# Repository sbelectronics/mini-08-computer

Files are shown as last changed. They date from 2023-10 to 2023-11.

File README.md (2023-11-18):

# Mini-08 Computer
### Scott Baker, https://www.smbaker.com/

## Description

The Mini-08 is a Single Board Computer (SBC) based on the Intel 8008 CPU, an 8-bit processor that was designed in approximately 1972. The Mini-08 has the following features

* 8008 CPU
* Up to 128 KB of RAM, mapped in 4K pages
* Up to 128 KB of ROM/EPROM/EEPROM, mapped in 4K pages
* On-board 8251 UART serial port
* 8 Onboard Diagnostic LEDs
* Support for interrupts
* A mostly-RC2014-compatible expansion bus connector

Also featured is an optional display board, which piggybacks on to the mini-08 and adds the following:

* Ten 7-segment hexadecimal display digits
* A 16-digit hexadecimal keypad
* Complex Sound Generator (3 music voices + 1 noise generator)
* Real-Time Clock

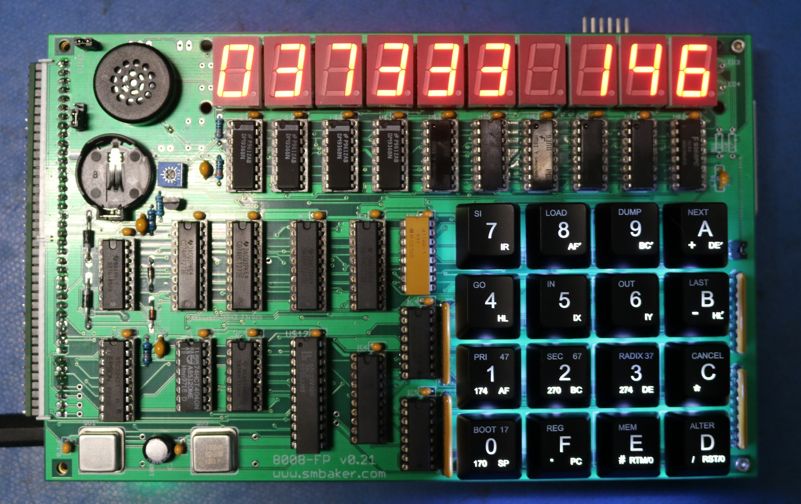
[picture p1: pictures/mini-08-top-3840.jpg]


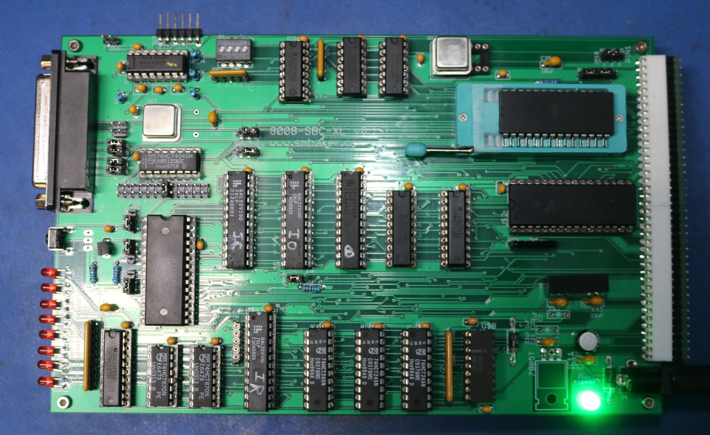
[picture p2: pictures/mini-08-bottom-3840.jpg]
CPU Board


Note that the 4th digit from the right is intentionally blank in these examples in software. The display is showing a
split-octal address (two groups of 3 digits) followed by an octal value (3 digits). All 10 displays are usable if you
decided to use alternate software.

## Alternate Display Board

In case the DM9368N drivers are hard to find or expensive, I have created a variant of the board that uses TIL311 integrated digits and drivers. They're also hard to
find and also expensive!

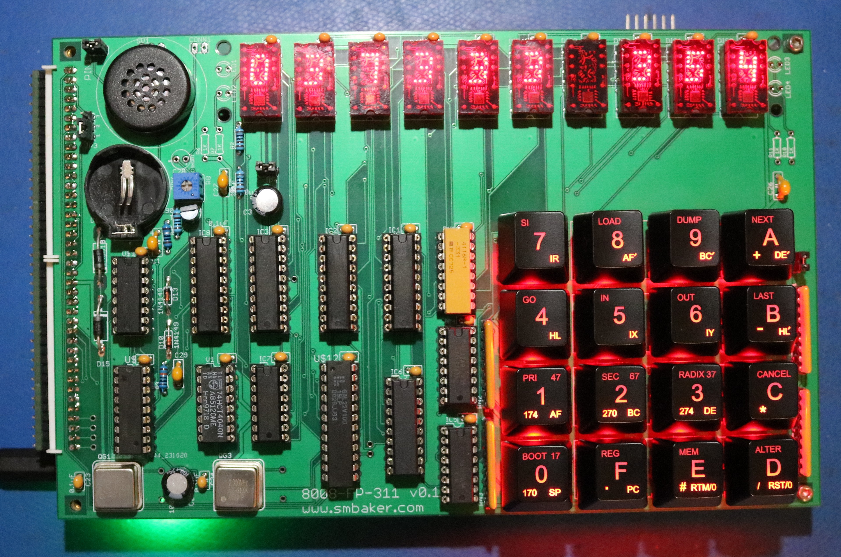
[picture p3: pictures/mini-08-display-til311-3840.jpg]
Display Board


The color of the backlit keys depends on the color of the LEDs you chose. In the TIL311 example, I went with red LEDs for the keys to have a matching
look. The LEDs are at the bottom center of the keys, so the keys are a little bit unevenly lit.

## Jumper Settings

### CPU Board

| Jumper | Position | Default | Description |
| --- | --- | ---| --- |
| SJ1  | 1-2 | X | Two page registers (74HCT670) installed |
| | 2-3 | | Only one page register installed |
| JP2, JP12 |  JP12-1  | | 115200 Baud |
| |  JP12-2  | | 57600 Baud |
| |  JP12-3  | | 38400 Baud |
| |  JP12-4  | | 19200 Baud |
| |  JP12-5  | | 9600 Baud |
| |  JP12-6  | | 4800 Baud |
| |  JP12-7  | | 2400 Baud |
| |  JP12-8  | | 1200 Baud |
| |  JP2-1 | | 600 Baud |
| |  JP2-2 | | 300 Baud |
| |  JP2-3 | | 150 Baud |
| |  JP2-4 | | 75 Baud |
| JP4  | 1-2 | | CTS follows DSR |
| | 2-3 | X | CTS always on |
| JP5  | 1-2 | X | MEMRD controlled by INTCON PLD |
| | 2-3 | | MEMRD directly controlled via bus PLD |
| JP9  | 1-2 | X | RTS is RTS |
| | 2-3 | | RTS is DTR |
| JP10 | 1-2 | X | RC2014-A8 is A12 |
| | 2-3 | | RC2014-A8 is GND |
| JP11 | 1-2 | X | Power-on CPUINT controlled by INTCON PLD |
| | 2-3 | | INTCON PLD bypassed, CPUINT directly controlled by POR |
| JP13 | | Present | Enable 8251 UART |

### Display Board

| Jumper | Position | Default | Description |
| --- | --- | ---| --- |
| SJ1  | | Present | RTC-CS is GND |
| JP1  | | Present | Onboard speaker is enabled |
| JP2  | | Present | Enable keypad backlight |
| JP3  | 1-2 | X | Front panel interrupt to INT pin |
| | 2-3 | | Front panel interrupt to FPINT pin (RC2014-A14) |

## Ports

The following describes the IO ports that I have allocated to various peripherals.

### Input

* 0 BB Serial / Dip Switches (internal)
* 1 Interrupt register (internal)
* 2 8251 UART - Data
* 3 8251 UART - Control
* 4 FP Keyboard
* 5 RTC
* 6 
* 7

### Output

* 8 BB Serial / LEDs (internal)
* 9 
* A FPEI (internal)
* B FPDI (internal)
* C mmap (internal)
* D mmap (internal)
* E mmap (internal)
* F mmap (internal)
* 10 Port multiplexer / RTC-ALE
* 11 Sound
* 12 8251 UART - Data
* 13 8251 UART - Conrol
* 14 
* 15 RTC
* 16 
* 17
* 18 FP Digits 0-1
* 19 FP Digits 2-3
* 1A FP Digits 4-5
* 1B FP Digits 6-7
* 1C FP Digits 8-9
* 1D FP Dots 0-7
* 1E FP Blanks 0-7
* 1F FP Dots 8-9, Blanks 8-9

Note to self: 18-1F were the IO Mapper on the H8 board. Some of my code may still output stuff to those ports.

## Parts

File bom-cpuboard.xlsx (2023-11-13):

Part | Value | Device | Package | Description | Mouser
C1,C3-C18,C20,C24-C38,C42 | 0.1uF | C-US025-025X050 | C025-025X050 | Various 0.1uF monolithic ceramic bypass caps
C19 | 100uf | CPOL-USE2.5-7 | E2,5-7 | POLARIZED CAPACITOR, American symbol | 667-ECE-A1EKS101I
C21,C22,C39-C44 | 10uF | C-US050-025X075 | C050-025X075 | Various 10uF monolithic ceramic caps, 5.08mm pitch
C23 | 1uF | C-US050-025X075 | C050-025X075 | Optional additional power supply filtering
D1 | 9V | TVS | DO15-12 | Optional 9V TVS protection diode | 576-SA9.0A
D4 | 5V | TVS | DO15-12 | Optional 5V TVS protection diode | 576-SA5.0A
DC1 |  | DCDC-SINGLETMV | TMV | DC-DC CONVERTER (if not using 7909 regulator) | 209-IVB0105S09
IC1 | 74HCT74N | 74HCT74N | DIL14 | Dual D type positive edge triggered FLIP FLOP, preset and clear | 595-SN74HCT74NE4
IC2 | 74HCT367N | 74HCT367N | DIL16 | Hex BUS DRIVER, 3-state | 595-CD74HCT367E
IC3,IC9,IC10 | 74HCT245N | 74HCT245N | DIL20 | Octal BUS TRANSCEIVER, 3-state | 595-SN74HCT245N
IC4 | 8251A | 8251A | DIL28-6 | Universal Syncronous/Asynchronous Receiver/Transmitter (USART) | jameco, utsource, ebay, etc
IC5,IC24 | 74HCT670N | 74HCT670N | DIL16 | 4 by 4 REGISTER FILES, 3-state | utsource, ebay, etc
IC6 | MAX202 | MAX202 | DIL16 | RS232 TRANSCEIVER | 700-MAX202CPE
IC7,IC12,IC18 | 74HCT273N | 74HCT273N | DIL20 | Octal D type FLIP FLOP, clear | 595-SN74HCT273N
IC11 | 7805T | 7805T | TO220H | +5V Regulator.Recommend pololu S13V15F5 instead
IC14 | 74HCT02N | 74HCT02N | DIL14 | Quad 2-input NOR gate | 595-SN74HCT02NE4
J4 | VIN | DCJACKNOSLOTS-BIGGER | DCJACK_NOSLOTS_BIGGER | DC POWER JACK
JP* |  |  |  | Various 1x2, 1x3, or 2x2 jumpers -- buy large and cut to size
LED0-LED7 |  | LED3MM | LED3MM | LED - 3MM RED
LED8 |  | LED5MM | LED5MM | LED - 5MM GREEN
QG1 | 4.9152MHz | XO-8 | DIL08S | Oscillator | 520-2100AX-049
QG3 | 1MHz | XO-8 | DIL08S | Oscillator | 520-TCH100-X
R1,R2 | 1K | R-US_0204/7 | 0204/7 | RESISTOR, American symbol
R3 |  | R-US_0204/2V | 0204V | RESISTOR, American symbol
R4,R5,R15 | 10K | R-US_0204/7 | 0204/7 | RESISTOR, American symbol
R6,R14,R23 | 2.2K | R-US_0204/2V | 0204V | RESISTOR, American symbol
RN1,RN7 | 1K | G08R | SIL9 | 1K by 8 resistors (9-pin) SIL RESISTOR
RN2 |  | G04R | SIL5 | SIL RESISTOR
RN3,RN6,RN9 | 10K | G04R | SIL5 | 10K by 8 resistors (9-pin) SIL RESISTOR
S2 |  | DS04 | DS-04 | 4-pin dip switch | 710-418117270904
SV1 |  | MA03-1 | MA03-1 | PIN HEADER
SV2 |  | MA05-1 | MA05-1 | PIN HEADER
SV3 |  | MA06-1 | MA06-1 | PIN HEADER
U$1 | ATF22V10-INTREG | ATF22V10 | DIL24-3 | GAL22V10D programmed with PLD/intreg | utsource, ebay, aliexpress "GAL22V10D-15LP"
U$2 | AS6C4008 | AS6C4008 | DIL32 | RAM, either AS6C4008 or AS6C1008 should work | 913-AS6C4008-55PCN
U$3 | ATF22V10-INTCON | ATF22V10 | DIL24-3 | GAL22V10D programmed with PLD/intcon | utsource, ebay, aliexpress "GAL22V10D-15LP"
U$4 | ATF22V10-BUS | ATF22V10 | DIL24-3 | GAL22V10D programmed with PLD/bus | utsource, ebay, aliexpress "GAL22V10D-15LP"
U$5 | ATF22V10-IO | ATF22V10 | DIL24-3 | GAL22V10D programmed with PLD/io | utsource, ebay, aliexpress "GAL22V10D-15LP"
U$6 | BUTTON_RA | BUTTON_RA | BUTTON_RA
U$7 | MCP130H | MCP130H | TO92- | Reset Supervisor IC | 579-MCP130-450HI/TO
U$8 | 8008 | 8008-FLP | DIL18 | 8008 CPU | ebay, aliexpress. ** be careful of counterfeits **
U$10 | RC2014 | RC2014 | SIP40 | 40-pin right angle sip socket
U$21 | 28C512-256 | 28C512-256 | DIL32-28-6-ZIF-SOCKET | EPROM/EEPROM/FL:ASH: 27C256, 28C256, 27C512, or 39SF010 | 804-39SF010A7CPHE
V1 | 744040N | 744040N | DIL16 | 12-bit asynchronous binary COUNTER
X2 |  | F25HP | F25HP | 25 pin female connector

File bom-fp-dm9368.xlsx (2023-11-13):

Part | Value | Device | Package | Description | Mouser
BAT1 |  | BATTERY20PTH | BATTCOM_20MM_PTH | Battery Holders
C1,C26,C27,C29 | 10uF | C-US050-025X075 | C050-025X075 | Various 10uF monolithic ceramic caps, 5.08mm pitch
C2-C24,C30,C31 | 0.1uF | C-US025-025X050 | C025-025X050 | Various 0.1uF monolithic ceramic bypass caps
C25 | 100uf | CPOL-USE2.5-7 | E2,5-7 | POLARIZED CAPACITOR, American symbol
C28 | SHORT | CPOL-USE2.5-5 | E2,5-5 | POLARIZED CAPACITOR, American symbol
D0-D9 |  | 7SEG-CK | 7SEG-13 | 7-segment DISPLAY | 859-LTS-6980HR
D10,D13 | 1N4149 | 1N4148DO35-7 | DO35-7 | DIODE
D14,D15 | 1N5819 | DIODE-DO15-12 | DO15-12 | DIODE
IC1,IC2,IC3,IC8 | 74HCT273N | 74HCT273N | DIL20 | Octal D type FLIP FLOP, clear
IC4,IC5 | 74LS148N | 74LS148N | DIL16 | 10-line to 4-line and 8-line to 3-line PRIORITY ENCODER
IC6 | 74HCT245N | 74HCT245N | DIL20 | Octal BUS TRANSCEIVER, 3-state
IC7 | 74ACT138N | 74ACT138N | DIL16 | 3-line to 8-line DECODER/DEMULTIPLEXER
JP* |  |  |  | Various 1x2, 1x3, or 2x2 jumpers -- buy large and cut to size
K0-KF |  | CHERRY-MX-LED | CHERRY-MX-LED |  | 540-MX1A-E1NW
LED1-LED4 |  | LED3MM | LED3MM | LED
QG1 | 3.57MHz | XO-8 | DIL08S | Oscillator | 520-TCH357-X 3.57
QG3 | 2MHz | XO-8 | DIL08S | Oscillator
R1,R2 | 330 | R-US_0204/7 | 0204/7 | RESISTOR, American symbol
R3 | 100K | R-US_0204/7 | 0204/7 | RESISTOR, American symbol
R4 | 1 | R-US_0204/7 | 0204/7 | RESISTOR, American symbol
R5,R6,R7,R10,R11 | 1K | R-US_0204/7 | 0204/7 | RESISTOR, American symbol
R8 | 20K | TRIM_US-CT6 | CT6 | POTENTIOMETER
RN1 | 330 | 8R-N | DIL16 | DIL RESISTOR
RN4,RN5 | 220 |  |  | 220 by 8 resistors (9-pin) SIL RESISTOR
RN2,RN3 | 10K | G08R | SIL9 | 10K by 8 resistors (9-pin) SIL RESISTOR
SP1 | SPEAKERPCB_MOUNT | SPEAKERPCB_MOUNT | PCB_MOUNT_SPEAKER | General speakers. | 490-CVS-2308
SV1 |  | MA03-1 | MA03-1 | PIN HEADER
T1 | 2N3904 | 2N3904 | TO92 | NPN TRANSISTOR
U$1-U$9,U$10 | DM9368N | DM9368N / F9368 | DIL16 | utsource
U$10 | RC2014 | RC2014 | SIP40 | 40-pin right angle sip socket
U$12 | ATF22V10 | ATF22V10 | DIL24-3 | GAL22V10D programmed with PLD/fp | utsource, ebay, aliexpress "GAL22V10D-15LP"
U$16 | RTC-72421 | RTC-72421 | DIL18 | real time clock
U$18 | 76489 | 76489 | DIL16 | complex sound generator
V1 | 744040N | 744040N | DIL16 | 12-bit asynchronous binary COUNTER | 595-CD74HCT4040E

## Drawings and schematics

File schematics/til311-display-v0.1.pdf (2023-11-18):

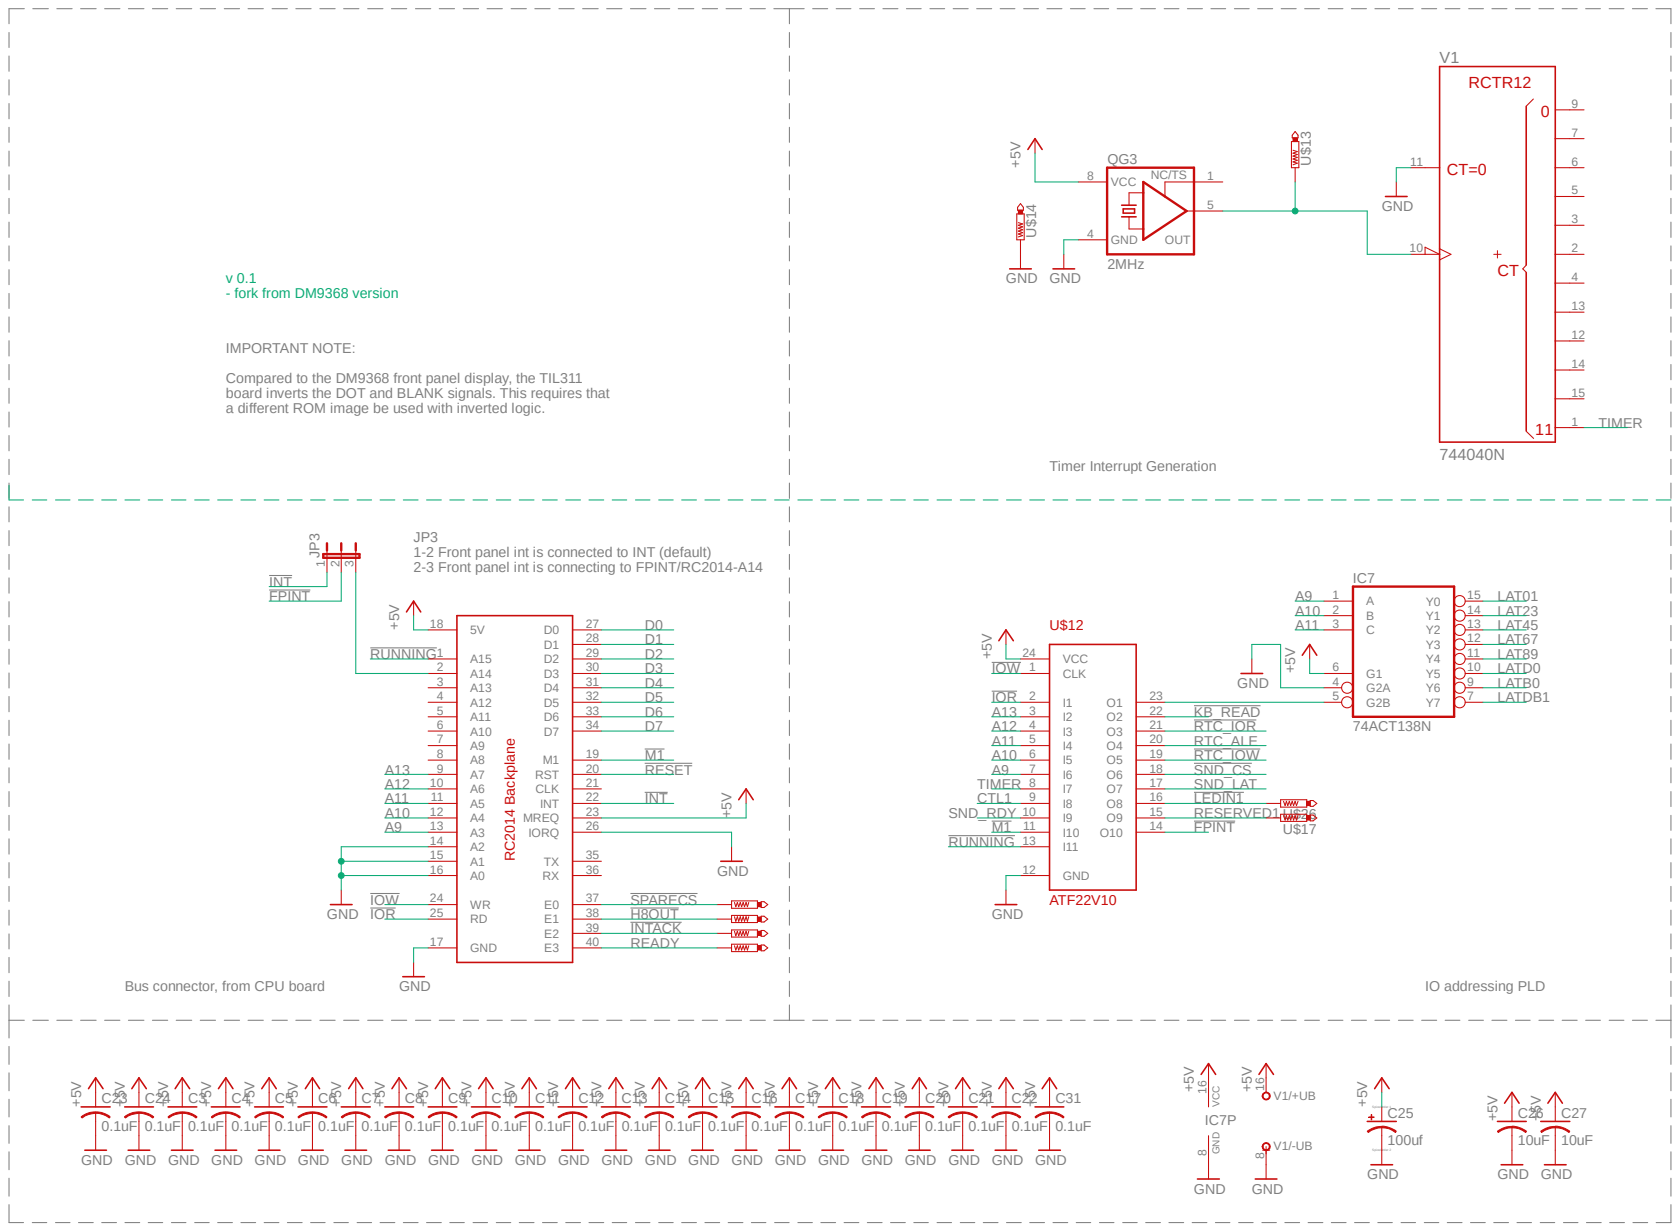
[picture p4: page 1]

Compared to the DM9368 front panel display, the TIL311
board inverts the DOT and BLANK signals. This requires that
a different ROM image be used with inverted logic.

1-2 Front panel int is connected to INT (default)
2-3 Front panel int is connecting to FPINT/RC2014-A14

Bus connector, from CPU board

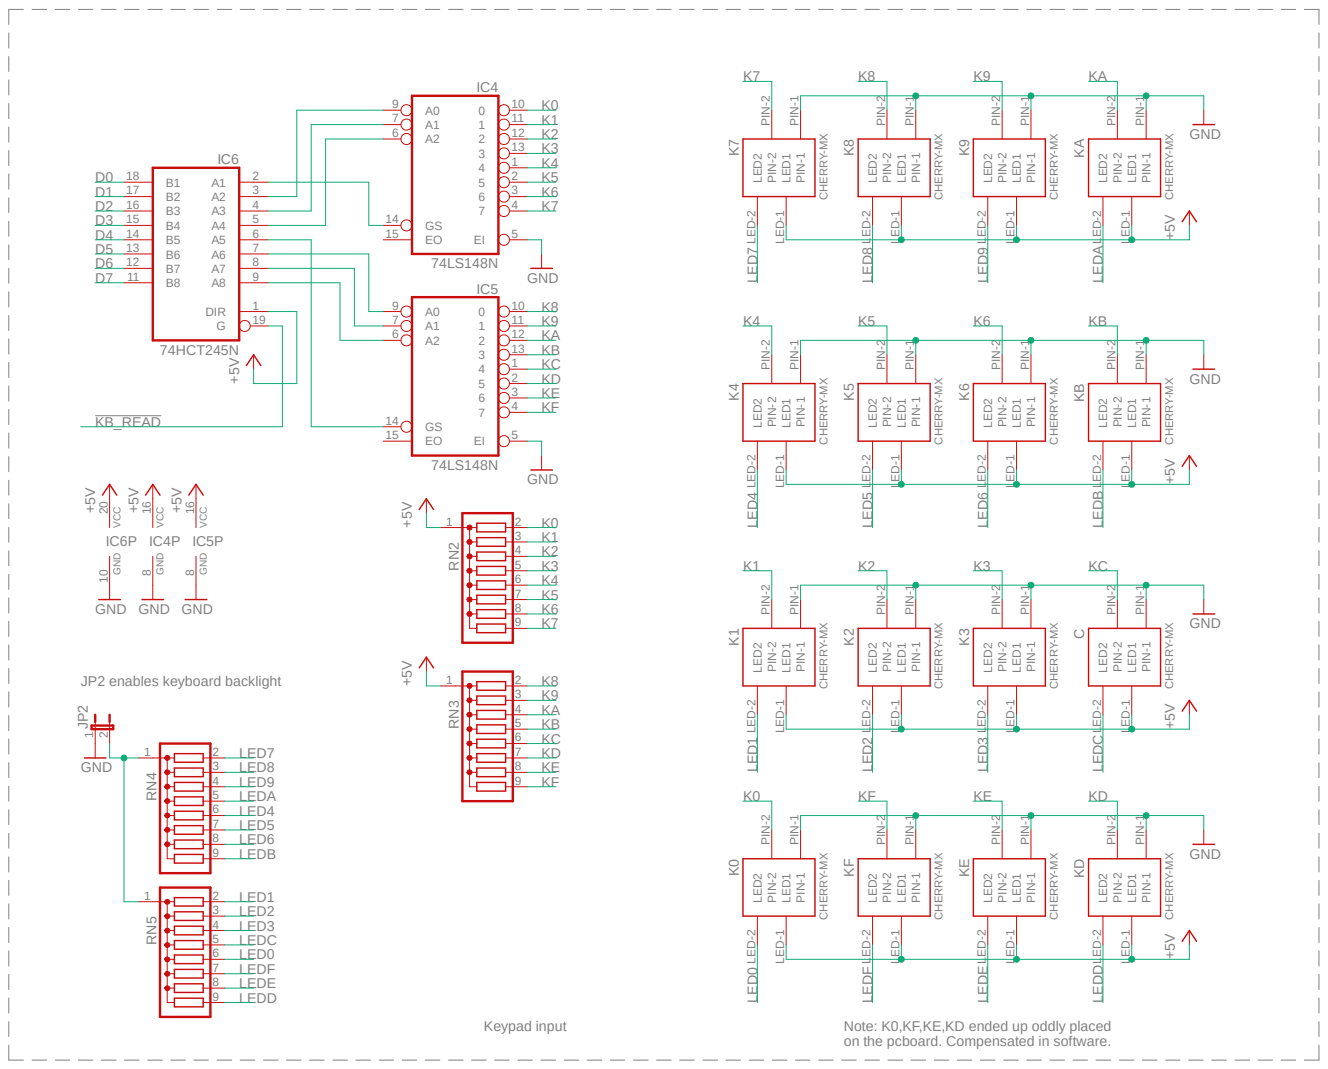
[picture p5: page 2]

Note: K0,KF,KE,KD ended up oddly placed
on the pcboard. Compensated in software.

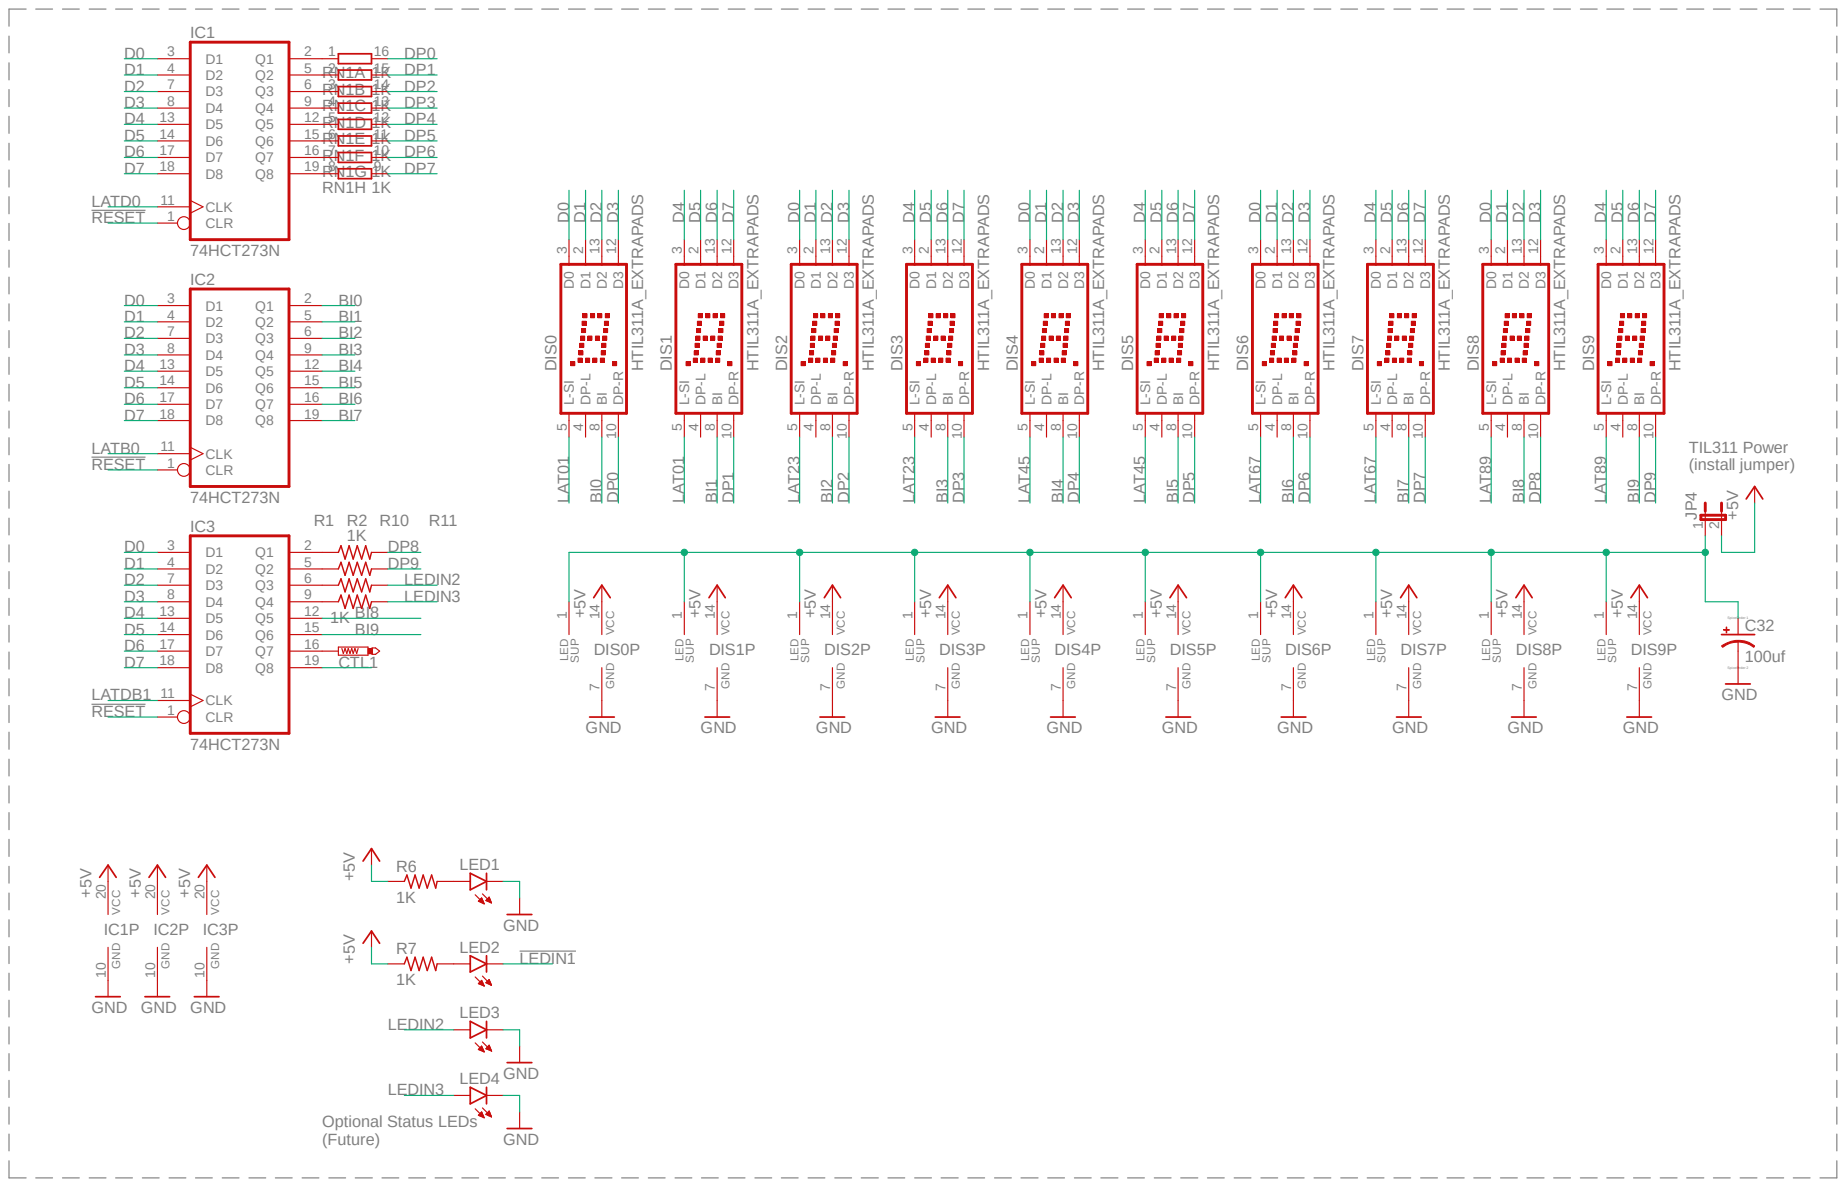
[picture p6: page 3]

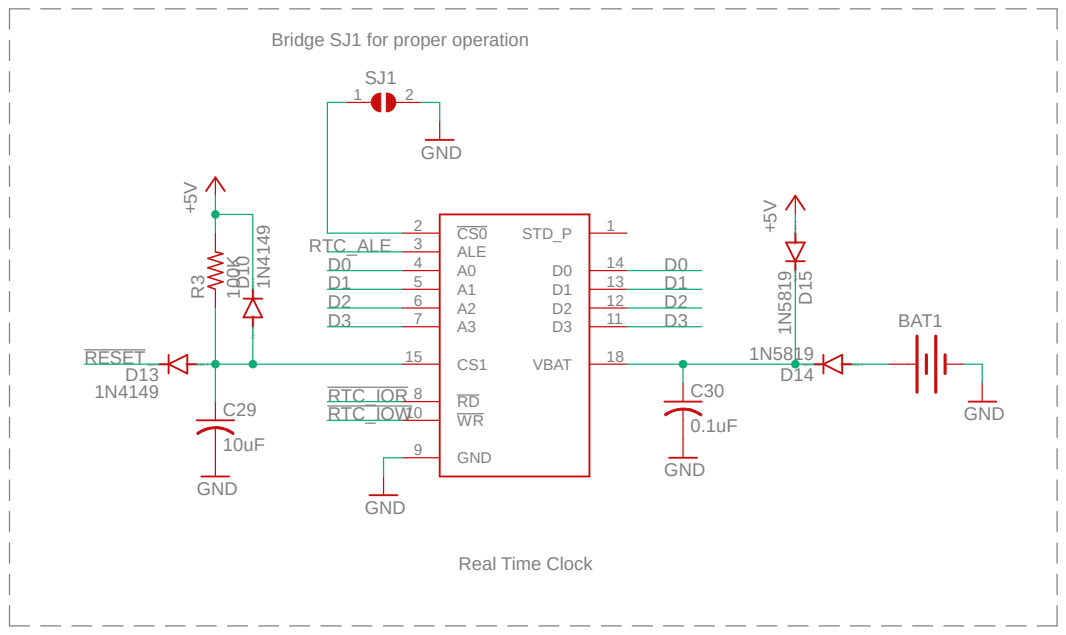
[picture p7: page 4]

Bridge SJ1 for proper operation

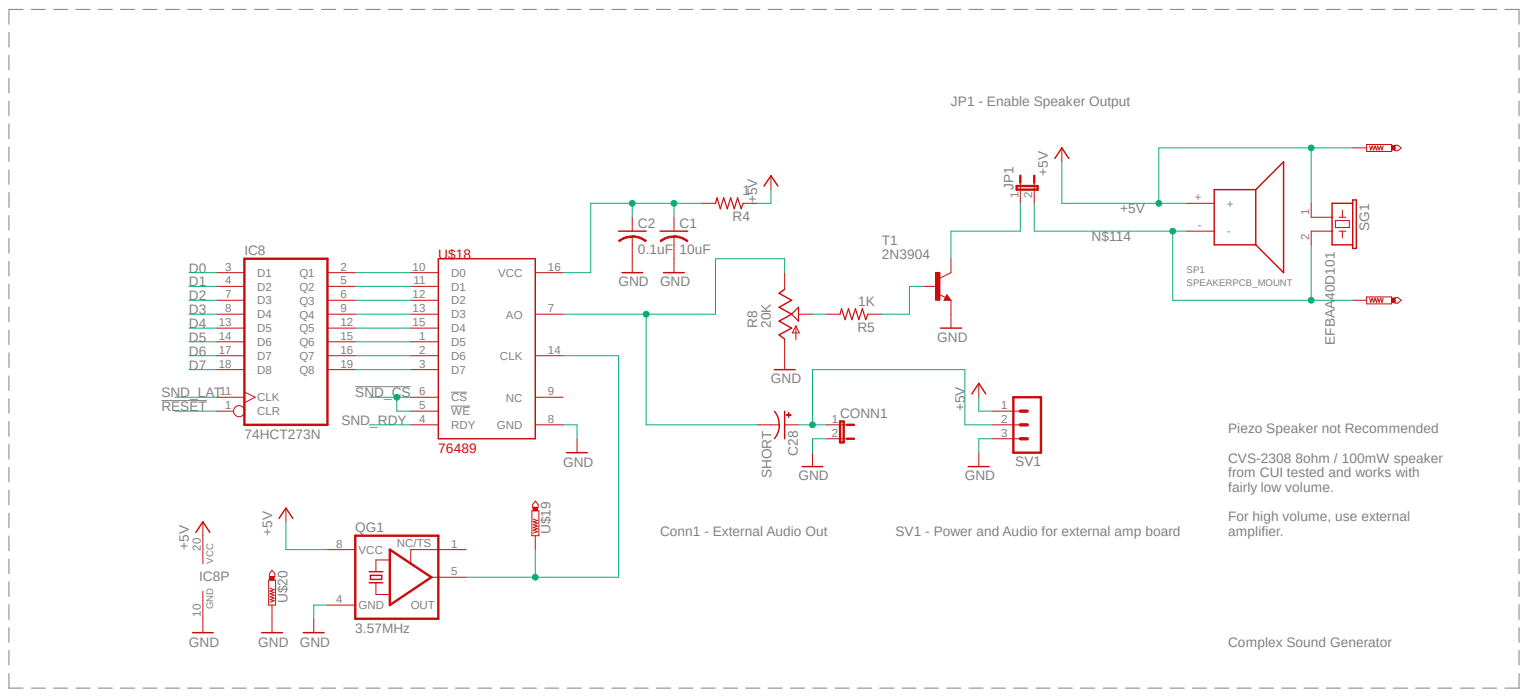
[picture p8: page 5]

Piezo Speaker not Recommended

CVS-2308 8ohm / 100mW speaker
from CUI tested and works with
fairly low volume.

For high volume, use external

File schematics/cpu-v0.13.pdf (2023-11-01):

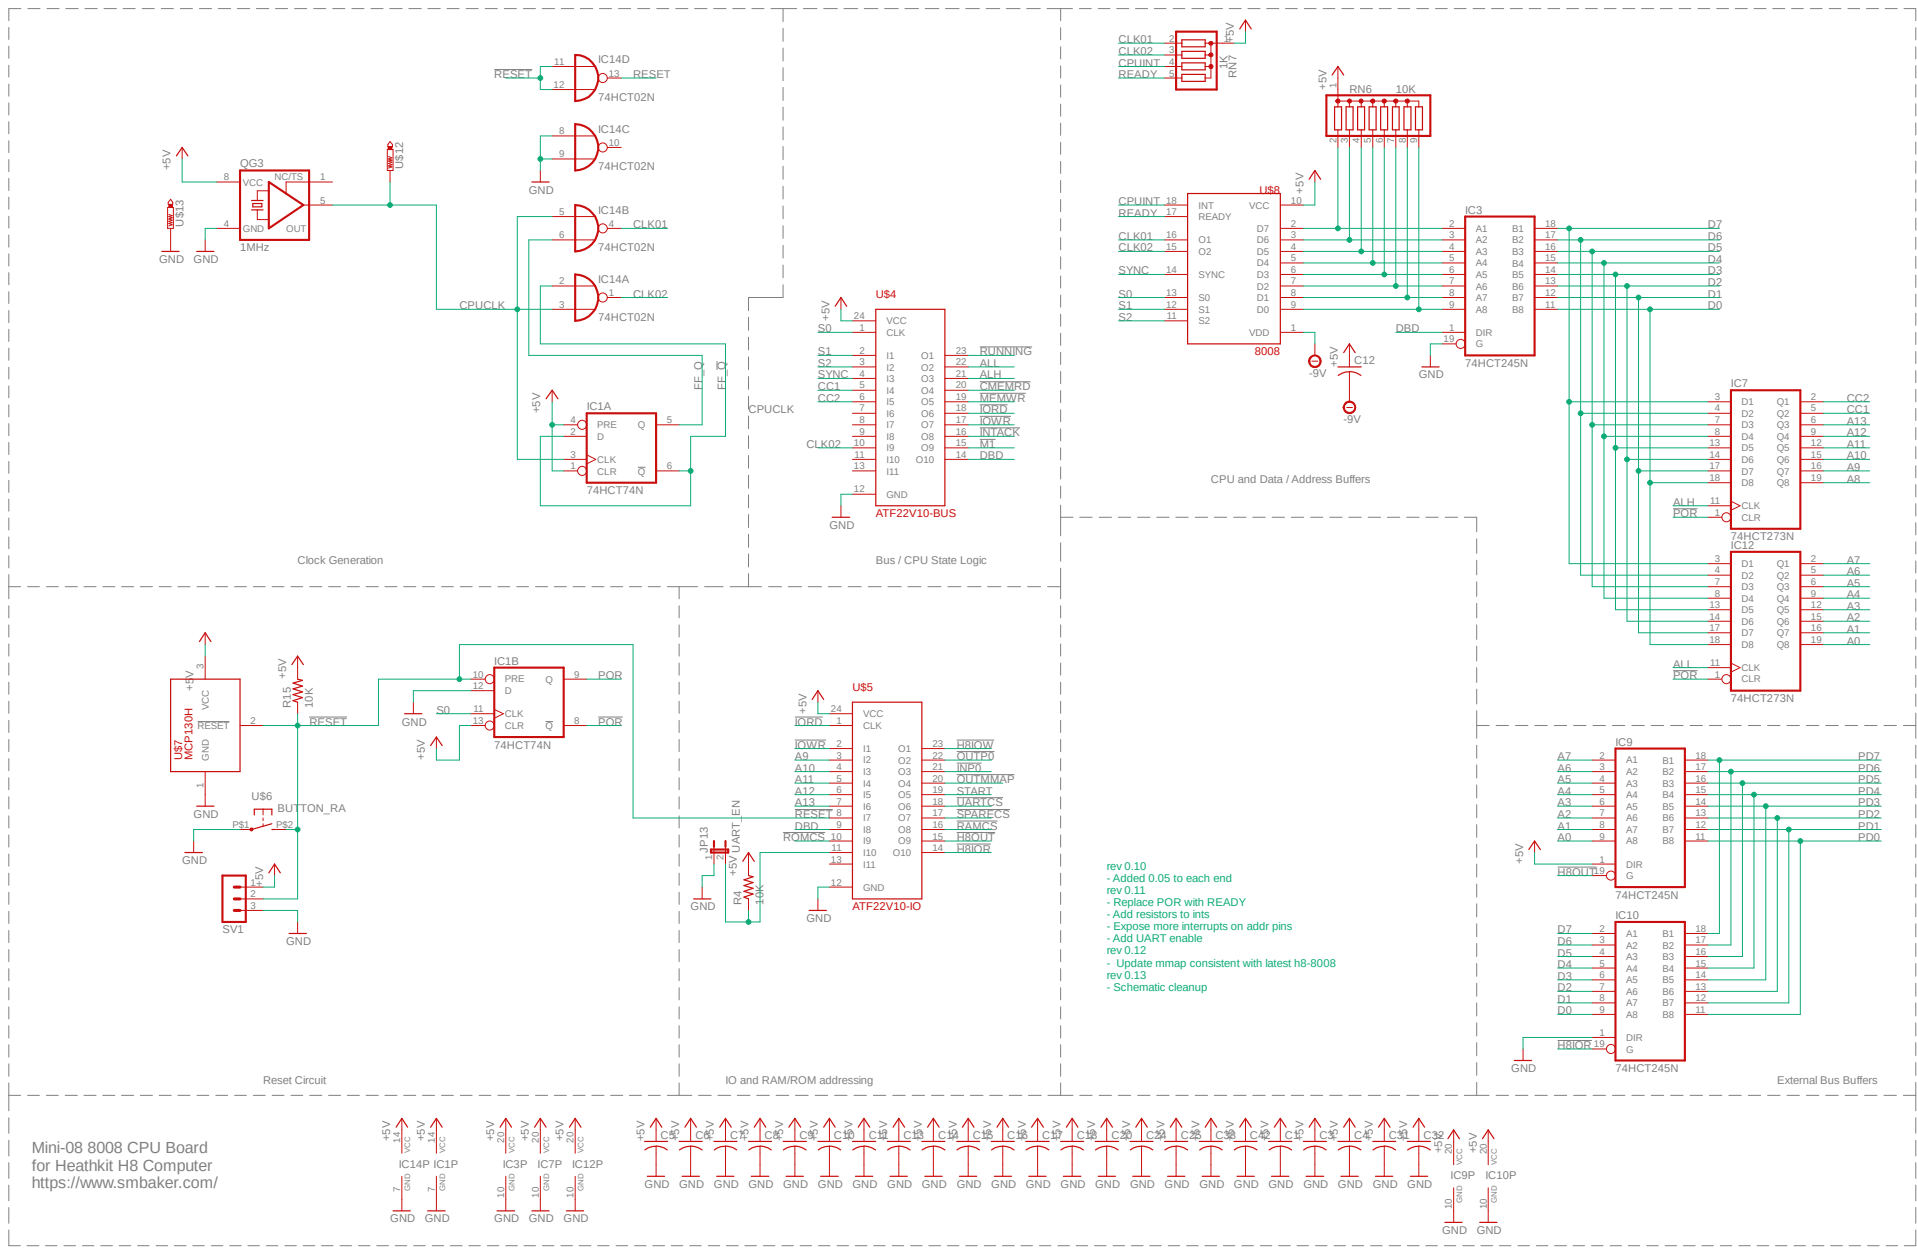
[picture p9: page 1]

A2 3
A3 4 | | D5

A5 6
A6 7 | D2
A7 8

CPU and Data / Address Buffers

rev 0.10
- Added 0.05 to each end
rev 0.11
- Replace POR with READY
- Add resistors to ints
- Expose more interrupts on addr pins
- Add UART enable
rev 0.12
- Update mmap consistent with latest h8-8008
rev 0.13
- Schematic cleanup

IO and RAM/ROM addressing

Mini-08 8008 CPU Board
for Heathkit H8 Computer
https://www.smbaker.com/

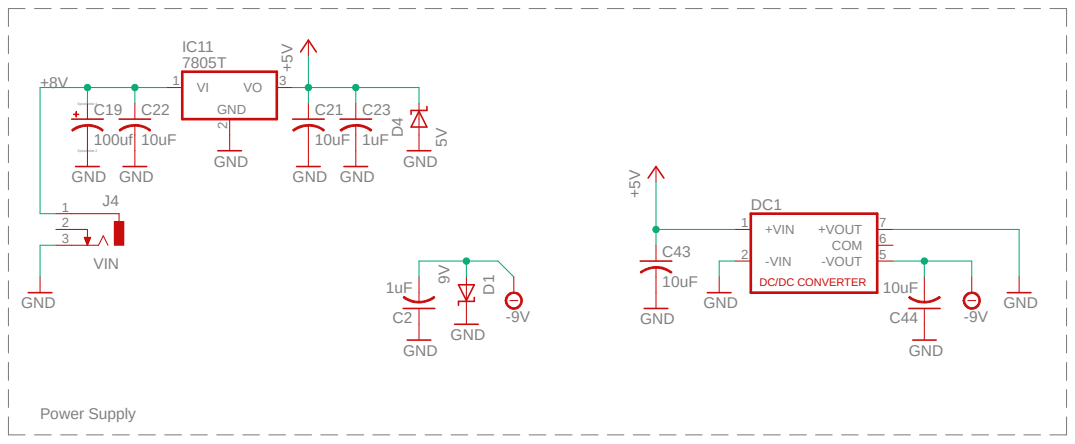
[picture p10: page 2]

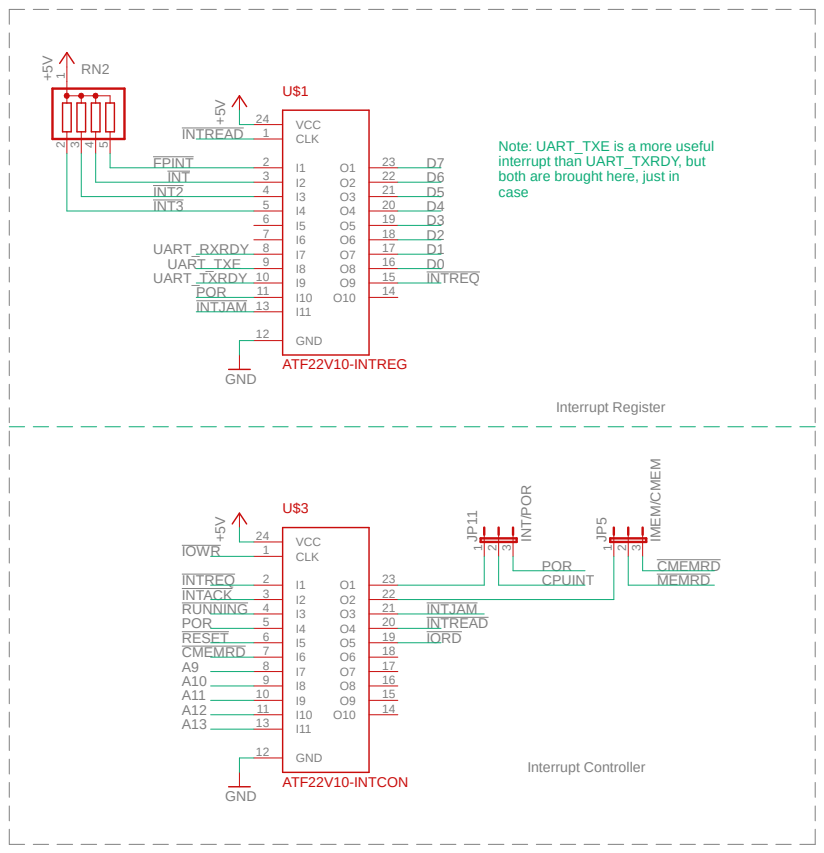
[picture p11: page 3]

Note: UART_TXE is a more useful
interrupt than UART_TXRDY, but
both are brought here, just in
case

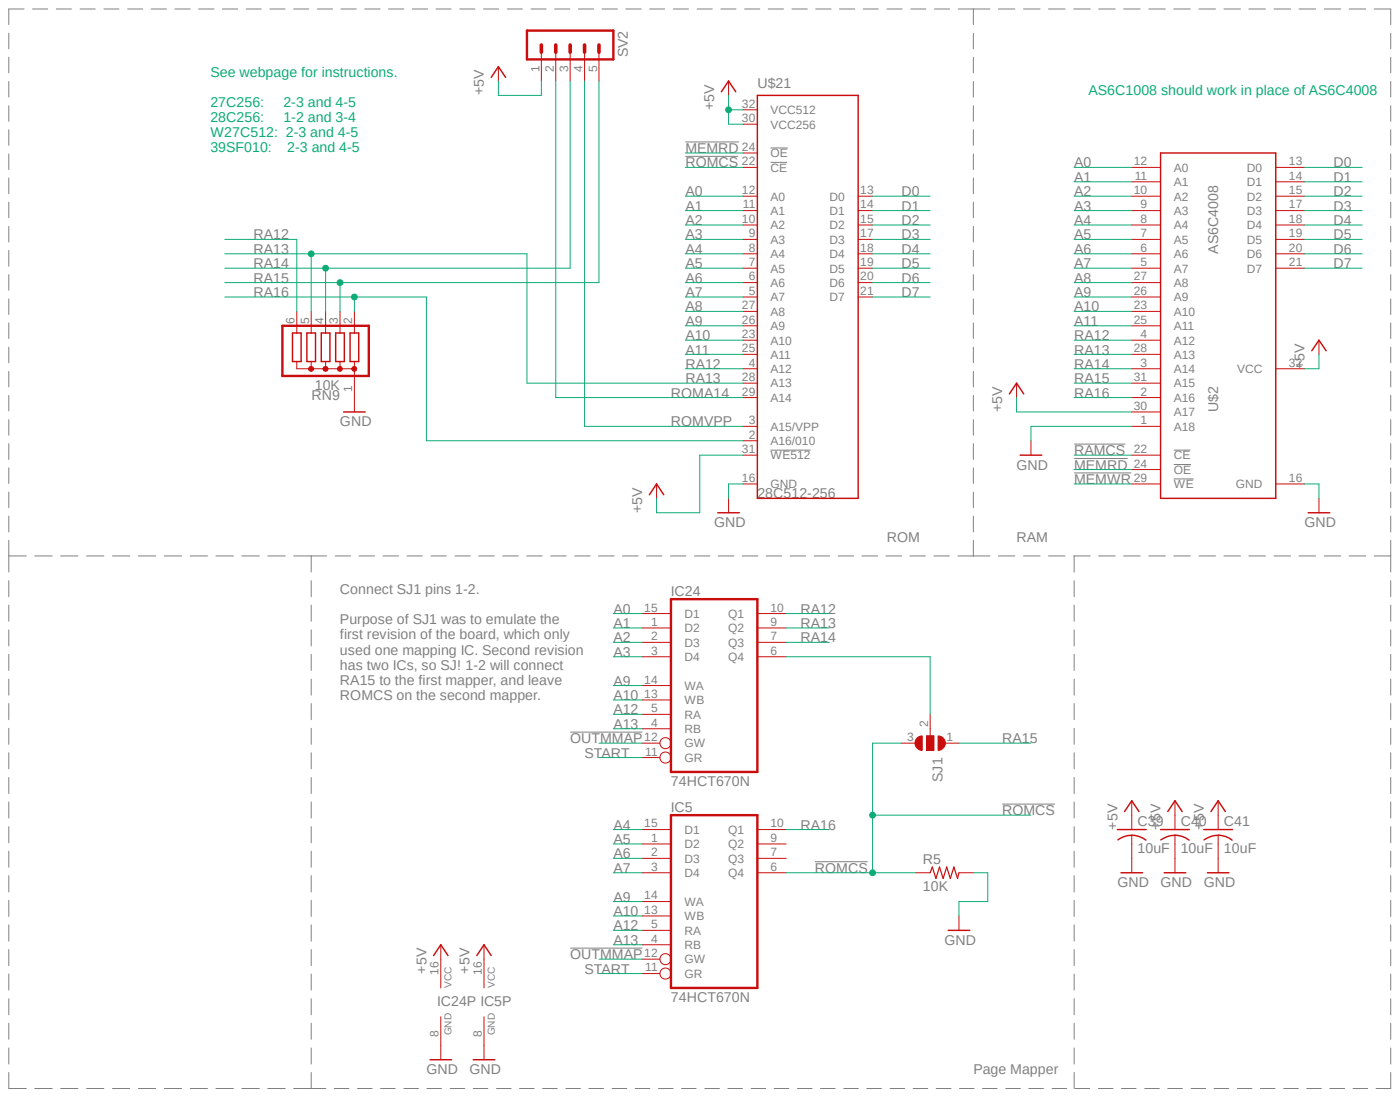
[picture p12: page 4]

See webpage for instructions.

AS6C1008 should work in place of AS6C4008

Purpose of SJ1 was to emulate the
first revision of the board, which only
used one mapping IC. Second revision
has two ICs, so SJ! 1-2 will connect
RA15 to the first mapper, and leave
ROMCS on the second mapper.

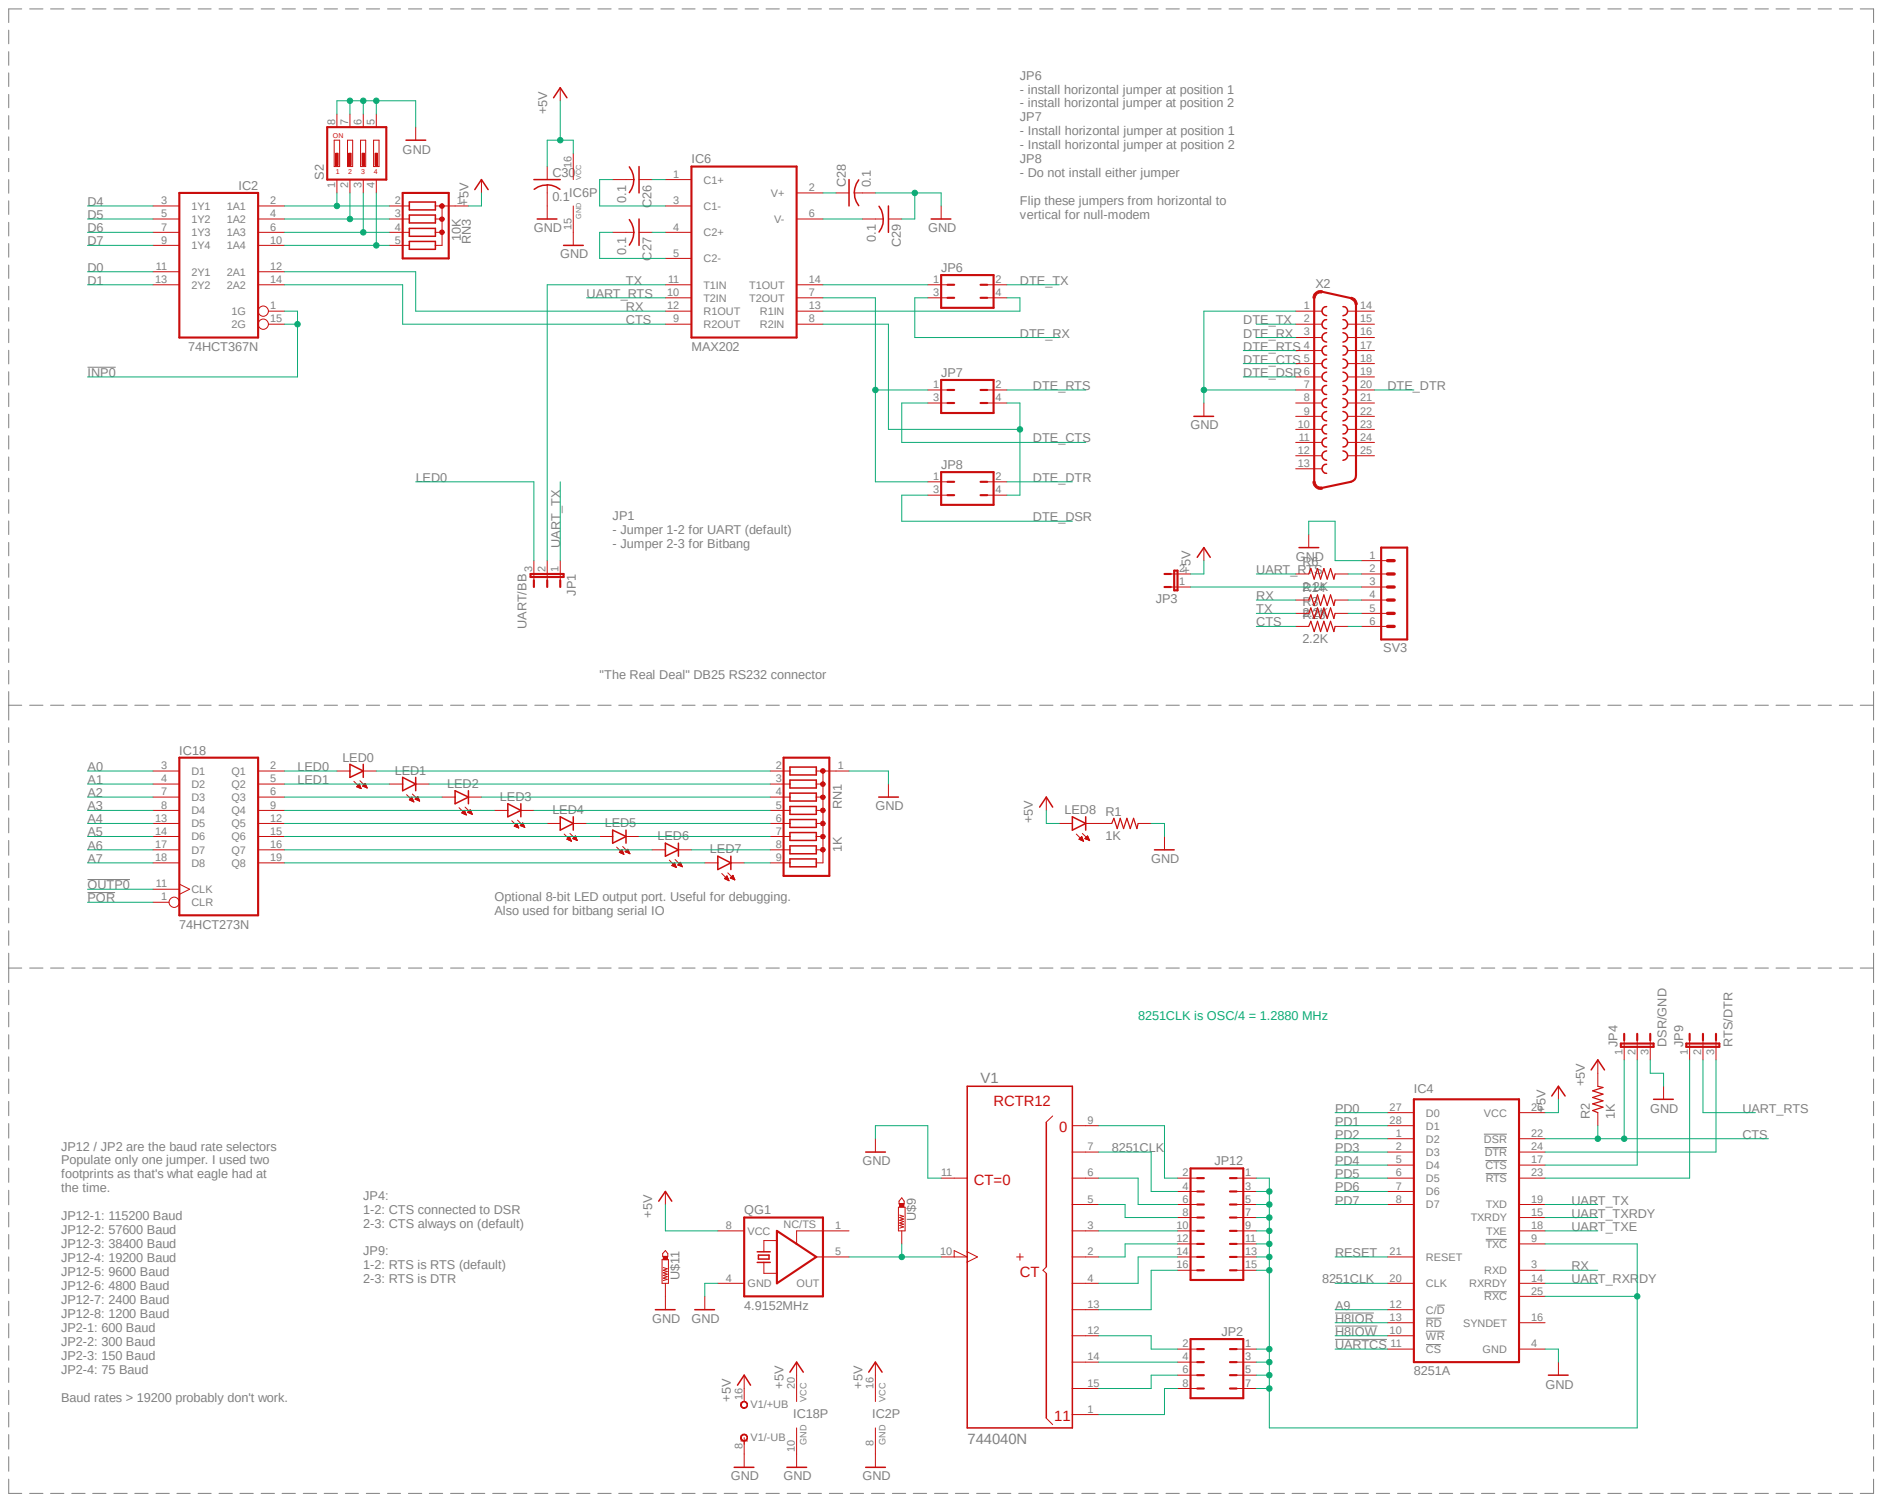
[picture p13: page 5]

- install horizontal jumper at position 1
- install horizontal jumper at position 2
- Install horizontal jumper at position 1
- Install horizontal jumper at position 2
- Do not install either jumper

Flip these jumpers from horizontal to
vertical for null-modem

- Jumper 1-2 for UART (default)
- Jumper 2-3 for Bitbang

"The Real Deal" DB25 RS232 connector

Optional 8-bit LED output port. Useful for debugging.
Also used for bitbang serial IO

JP12 / JP2 are the baud rate selectors
Populate only one jumper. I used two
footprints as that's what eagle had at
the time.

1-2: CTS connected to DSR
2-3: CTS always on (default)

1-2: RTS is RTS (default)
2-3: RTS is DTR

Baud rates > 19200 probably don't work.

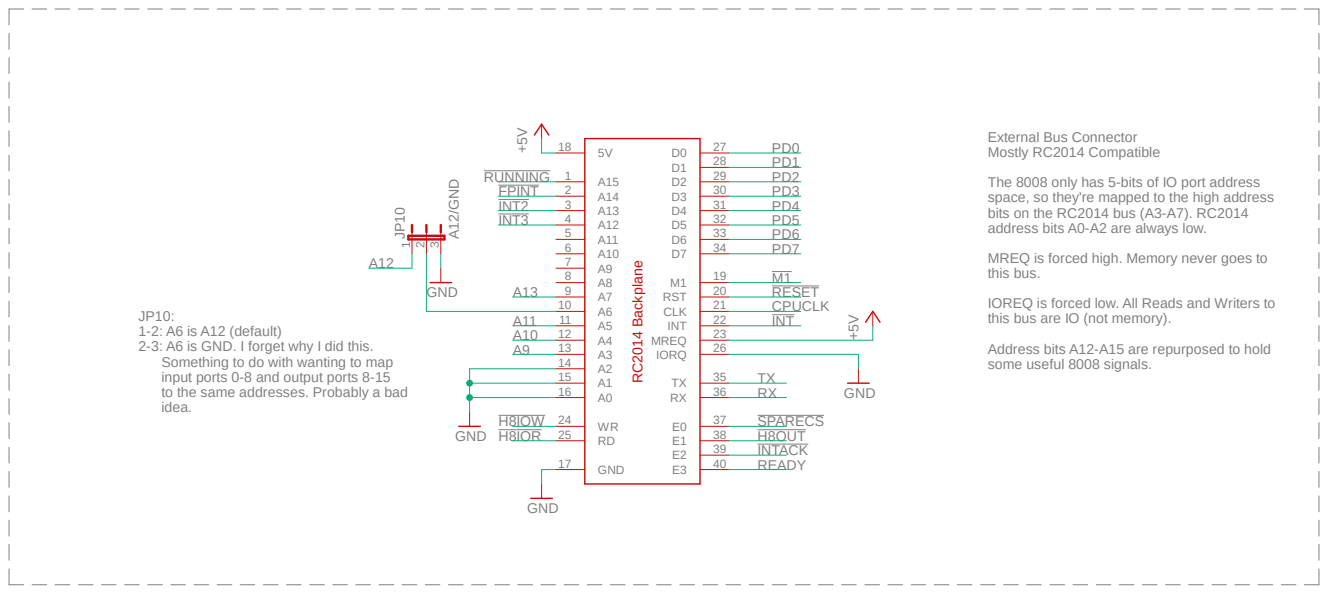
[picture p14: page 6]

The 8008 only has 5-bits of IO port address
space, so they're mapped to the high address
bits on the RC2014 bus (A3-A7). RC2014
address bits A0-A2 are always low.

MREQ is forced high. Memory never goes to
this bus.

IOREQ is forced low. All Reads and Writers to
this bus are IO (not memory).

1-2: A6 is A12 (default)
2-3: A6 is GND. I forget why I did this.
Something to do with wanting to map
input ports 0-8 and output ports 8-15
to the same addresses. Probably a bad
idea.

Address bits A12-A15 are repurposed to hold
some useful 8008 signals.

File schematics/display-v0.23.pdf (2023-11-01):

V1

0

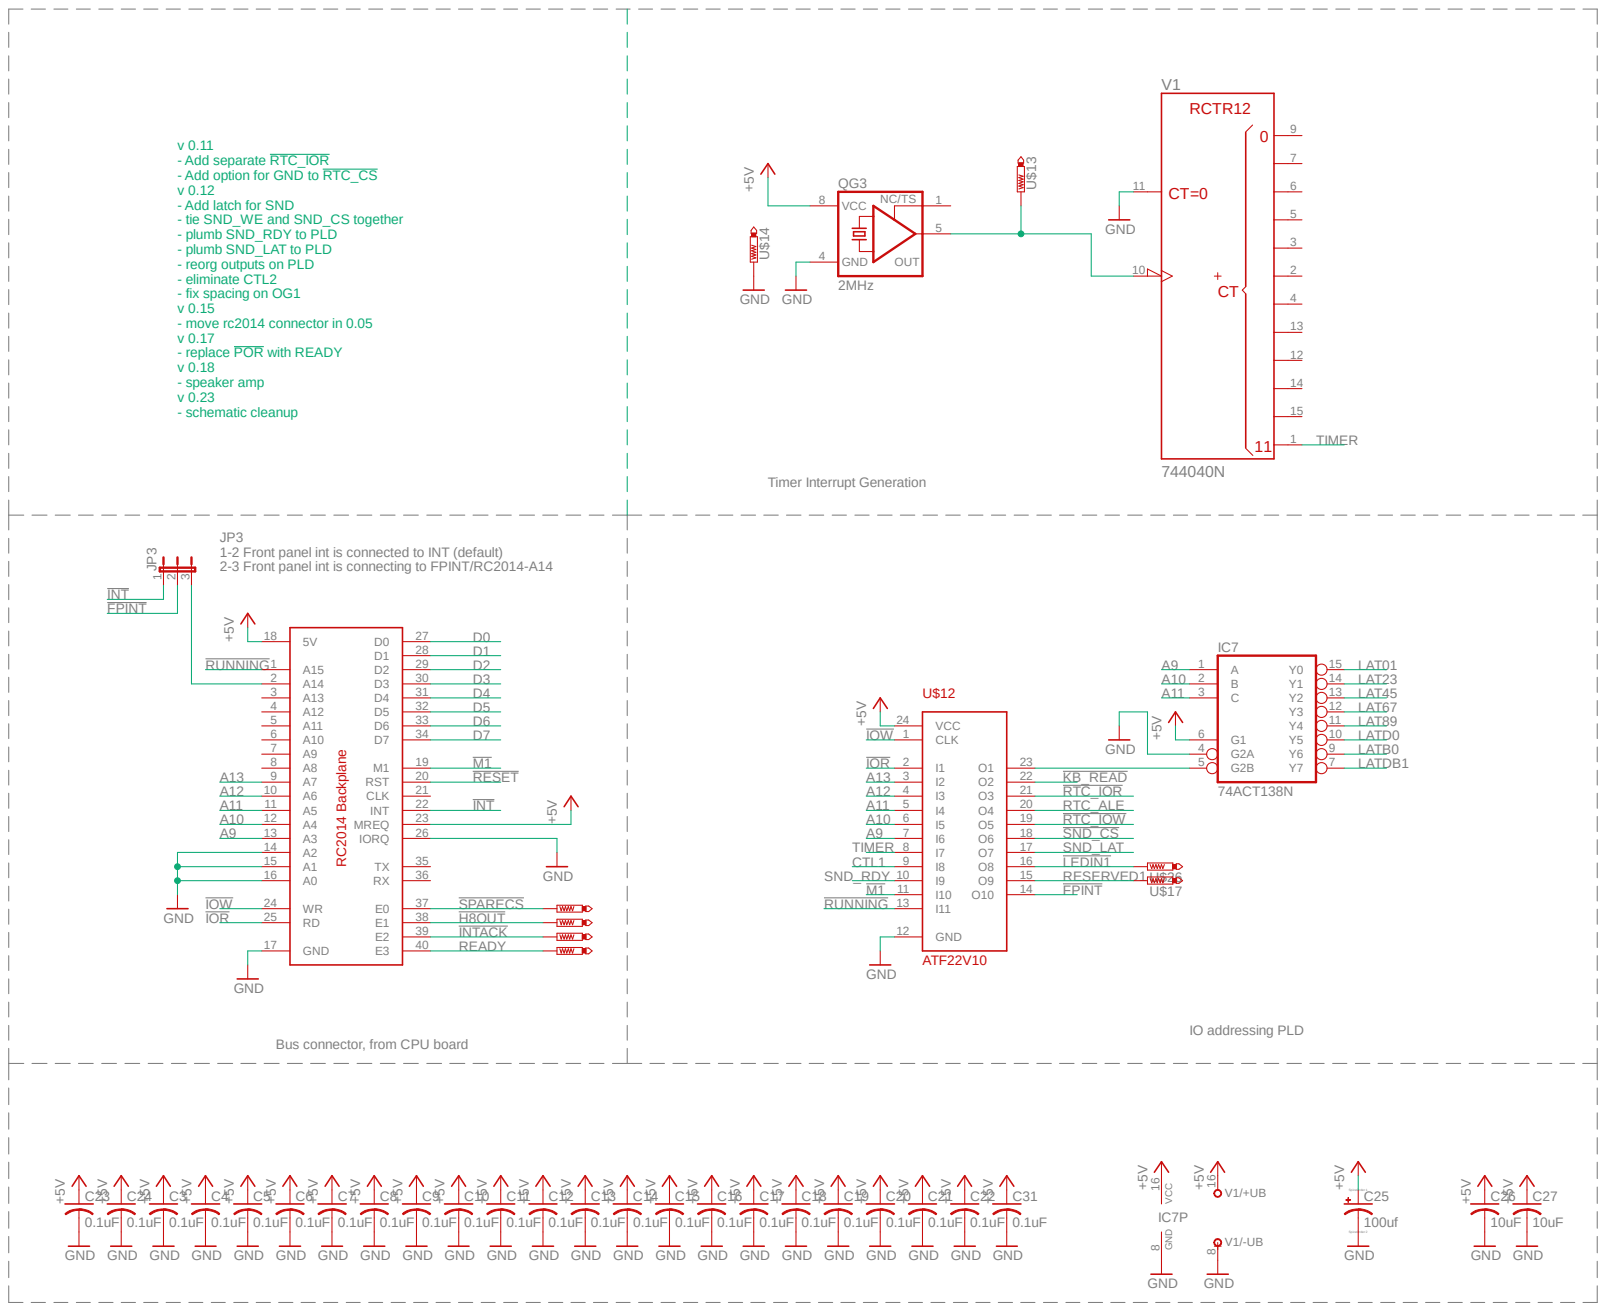
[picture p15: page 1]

- Add separate RTC_IOR
- Add option for GND to RTC_CS
- Add latch for SND
- tie SND_WE and SND_CS together
- plumb SND_RDY to PLD
- plumb SND_LAT to PLD
- reorg outputs on PLD
- eliminate CTL2
- fix spacing on OG1
- move rc2014 connector in 0.05
- replace POR with READY
- speaker amp
- schematic cleanup

1-2 Front panel int is connected to INT (default)
2-3 Front panel int is connecting to FPINT/RC2014-A14

Bus connector, from CPU board

## GND

IC4


Note: K0,KF,KE,KD ended up oddly placed
on the pcboard. Compensated in software.



Bridge SJ1 for proper operation


Piezo Speaker not Recommended

CVS-2308 8ohm / 100mW speaker
from CUI tested and works with
fairly low volume.

For high volume, use external
amplifier.

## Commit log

2023-10-31 check in gerbers
    [8008-sbc-frontpanel.GBL, 8008-sbc-frontpanel.GBO, 8008-sbc-frontpanel.GBS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]
2023-11-01 check in schematics
2023-11-13 check in BOMs
    [bom-cpuboard.xlsx, bom-fp-dm9368.xlsx, bom-fp-til311.xlsx]
2023-11-18 check in til311 schematics
2023-11-18 check in gerbers and rom images
    [8008-sbc-frontpanel-til311.GBL, 8008-sbc-frontpanel-til311.GBO, 8008-sbc-frontpanel-til311.GBS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]
